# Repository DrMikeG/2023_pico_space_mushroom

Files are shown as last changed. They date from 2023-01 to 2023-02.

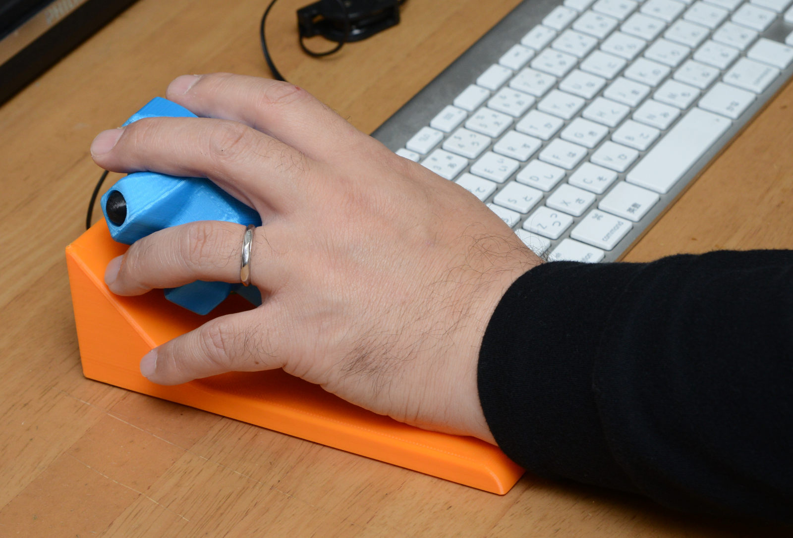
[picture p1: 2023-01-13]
Space_Mushroom___Full_6_DOFs_Space_Mouse_5739462/images/base1s.jpg

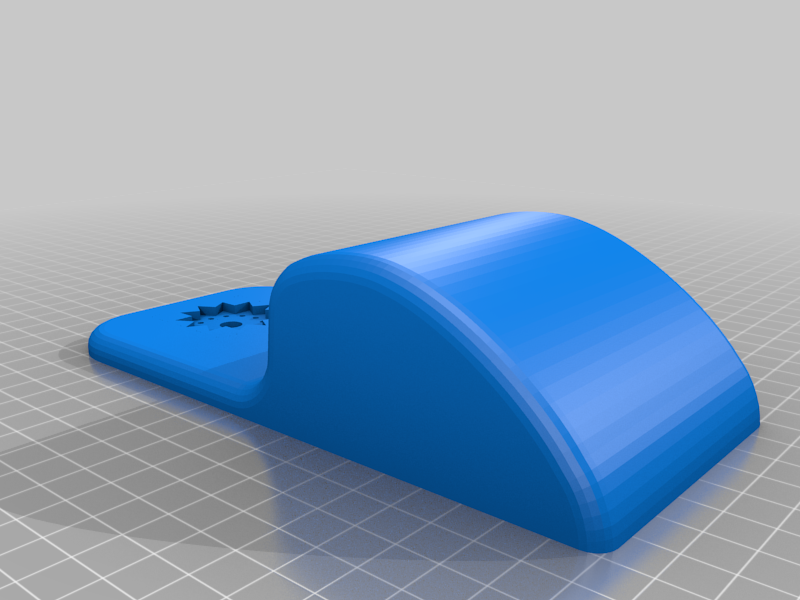
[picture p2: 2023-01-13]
Space_Mushroom___Full_6_DOFs_Space_Mouse_5739462/images/horizontal-base.png

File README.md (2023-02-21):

# 2023_pico_space_mushroom

https://www.thingiverse.com/thing:5739462

I've started printing the parts - beginning with the big knob.

I've ordered:

```WMYCONGCONG 5 PCS Joystick Breakout Module Game Controller for Arduino PS2 + 120 PCS Multicolored Breadboard Jumper Wires Ribbon Cables Kit```

Because I think they match the dimensions used by the OP.

```BGTXINGI 800PCS 8 Kinds M2 Nickel-Plate Flat Head Self Tapping Screw Stainless Sheet Wood Screw Assortment Kit Collected in A Convenient Case```

For assembly

And because I plan to use a pico, which only has 3 ADCs (and I need 6 inputs) - 

```SparkFun Analog/Digital MUX Breakout - CD74HC4067```

> This is a breakout board for the very handy 16-Channel Analog/Digital Multiplexer/Demultiplexer CD74HC4067. This chip is like a rotary switch - it internally routes the common pin (COM in the schematic, SIG on the board) to one of 16 channel pins (CHANxx).
>
> It works with both digital and analog signals (the voltage can’t be higher than VCC), and the connections function in either direction. To control it, connect 4 digital outputs to the chip’s address select pins (S0-S3), and send it the binary address of the channel you want (see the datasheet for details). This allows you to connect up to 16 sensors to your system using only 5 pins!
>
> Since the mux/demux also works with digital signals, you can use it to pipe TTL-level serial data to or from multiple devices. For example, you could use it to connect the TX pins of 16 devices to one RX pin on your microcontroller. You can then select any one of those 16 devices to listen to. If you want two-way communications, you can add a second board to route your microcontroller’s TX line to 16 device’s RX lines. By using multiple boards, you can create similar arrangements for I2C, SPI, etc.
>
> The internal switches are bidirectional, support voltages between ground and VCC, have low “on” resistance and low “off” leakage, and to prevent crosstalk, perform “break-before-make” switching. The board also breaks out the chip’s “enable” pin, which when driven high, will completely disconnect the common pin (all switches “off”).
>
> Features:
> 2V to 6V operation
> “On” resistance: 70 Ohms @ 4.5V
> 6ns break-before-make @ 4.5V
> Wide operating temperature range: -55C to 125C
> Documents:
> - https://www.sparkfun.com/datasheets/IC/cd74hc4067.pdf
> - https://github.com/sparkfun/Analog_Digital_MUX_Breakout

> Do note that the enable pin, EN, is active low. The description says this but I don't read...
> Use this to read sixteen inputs or to control sixteen outputs (or any combination thereof) using only six pins from you micro (five pins if you hold EN low via hardwire).

Let's go study the example code.

It acts as both a mouse and keyboard. Can the pico do this?

https://learn.adafruit.com/circuitpython-essentials/circuitpython-hid-keyboard-and-mouse

I wired up the joystick modules to the pico, and read the dx and dy values.

They seem are sensitive enough for left vs right, but the granularity seems very low, especially for higher values.
Also, pushing fully up seems to register as full up and full right. I've ordered some more.

Going to check one I've not soldered - perhaps the heat damaged the pots?
- No, warehouse soldered ones are just as crappy.

Wait for new supplies.

5 New, equally crappy looking joystick modules arrived. Same B103 pots. New boards don't even have the corners rounded off.
Got exactly the same behaviour when plugged in - considered that it could be because I was supplying 5V and then reading it with a 3V ADC.

Swapped power to joystick to 3V and they behave much more predictably. Hopefully my ADC is not damaged.

Pan in our app is
left-shift + middle mouse button press + mouse move up/down left/right

![Alt text](./readme_img/Raspberry-Pi-Pico-pinout-diagram.svg)

## Joystick failure ## 

I had a burnt out joystick module. The joystick was registering 3v3 on both axis all the time. Swapped it out.

## Mouse acceleration ##

Using 10_ and 11_ I figured out what I couldn't get the mouse to return the starting position.

Windows takes the instruction (10,24) and applies an acceleration factor so who knows what it might move by.

So, no hope of making it return to the starting position.

I did however learn the polling him for the USD HID is only 8ms - so I can probably reduce my delays quite a lot.

I also fixed a bug in deaden and using ceiling for negative numbers.

Now working on 12_

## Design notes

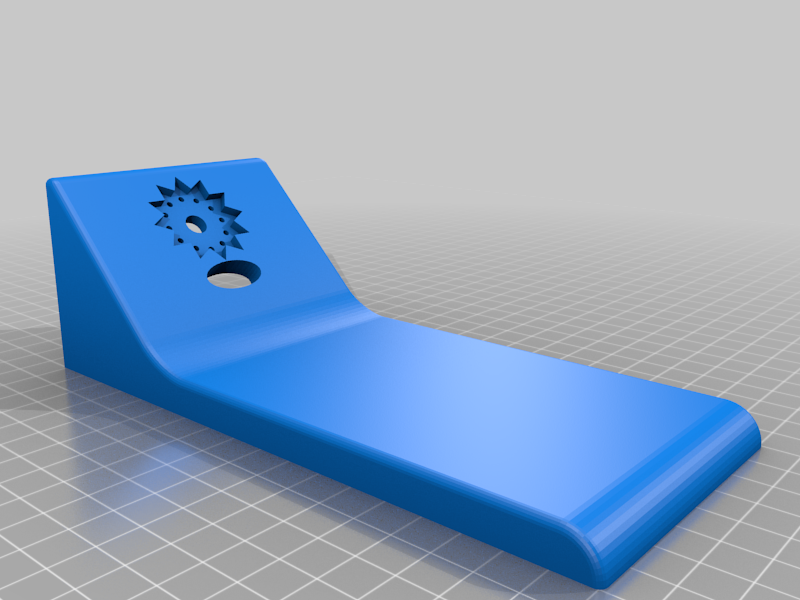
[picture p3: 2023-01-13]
Space_Mushroom___Full_6_DOFs_Space_Mouse_5739462/images/tilted-base.png

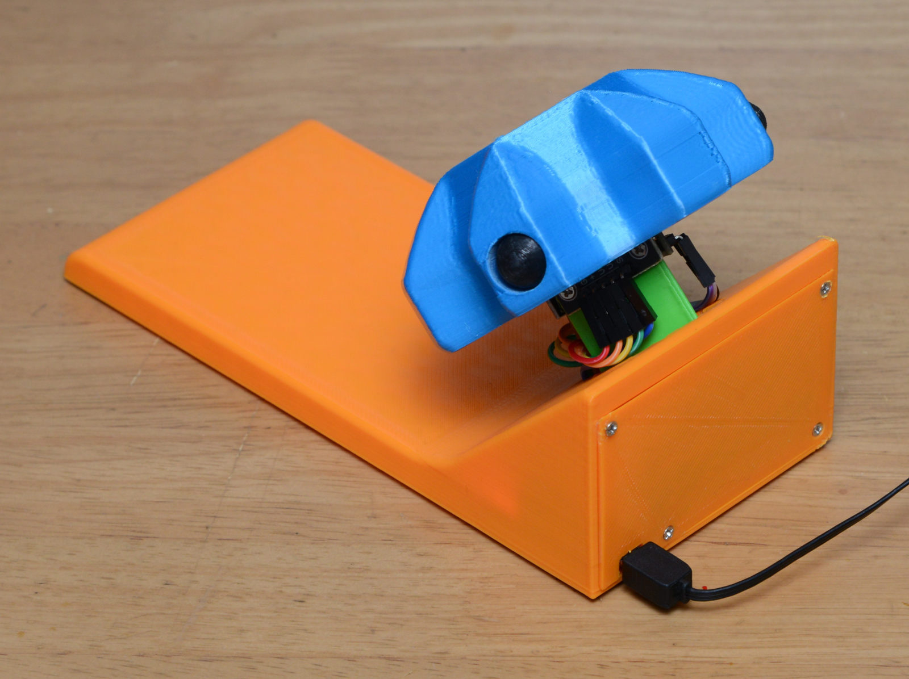
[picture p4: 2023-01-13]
Space_Mushroom___Full_6_DOFs_Space_Mouse_5739462/images/base4s.jpg

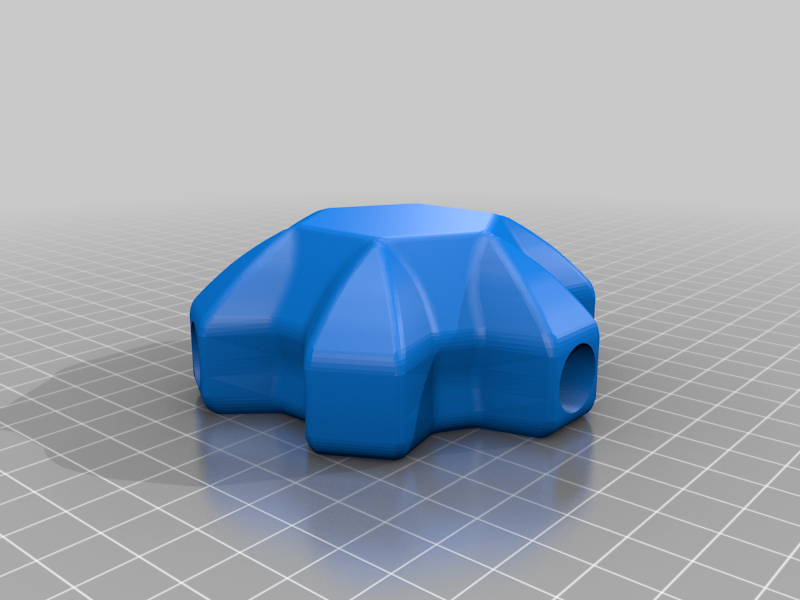
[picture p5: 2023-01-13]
Space_Mushroom___Full_6_DOFs_Space_Mouse_5739462/images/knob.png

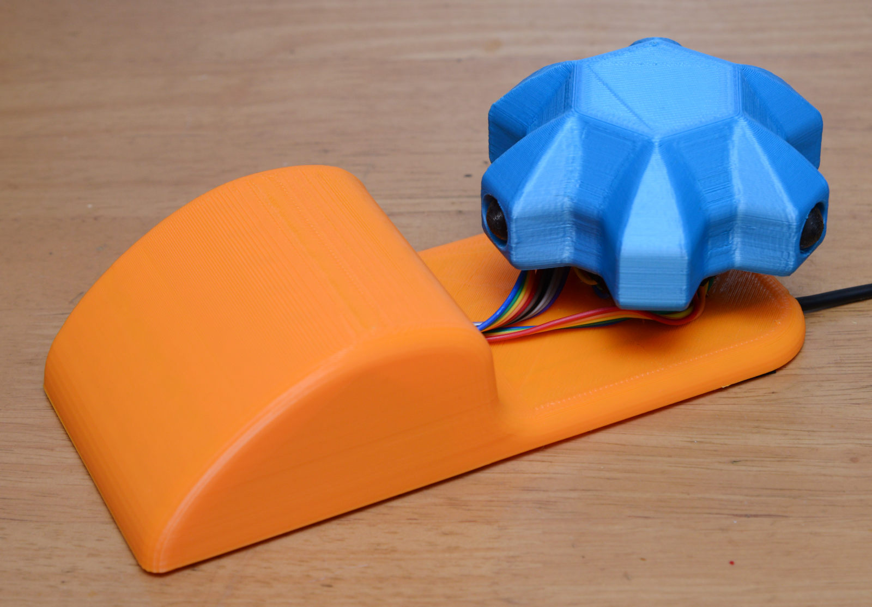
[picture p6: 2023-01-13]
Space_Mushroom___Full_6_DOFs_Space_Mouse_5739462/images/horizontal1s.jpg

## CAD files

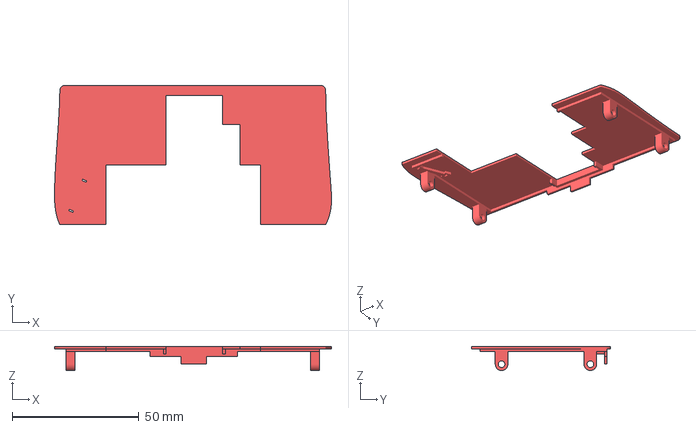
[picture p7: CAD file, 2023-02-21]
parts/mounting_lid_right_04.3mf
109.4 x 55.0 x 9.50 mm

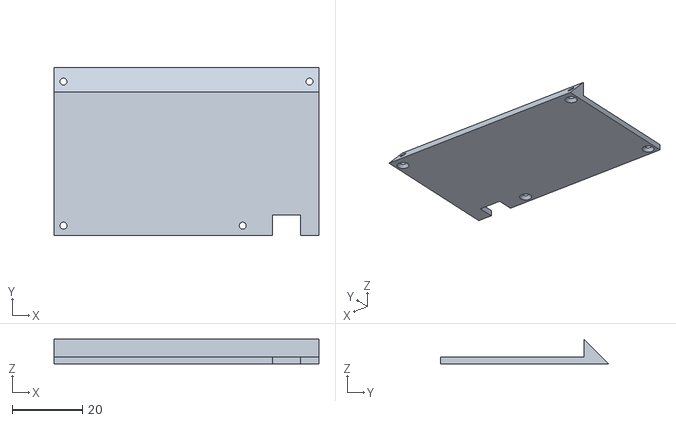
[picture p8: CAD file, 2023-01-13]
Space_Mushroom___Full_6_DOFs_Space_Mouse_5739462/files/tilted-rear-cover.stl
75.4 x 47.8 x 7.00

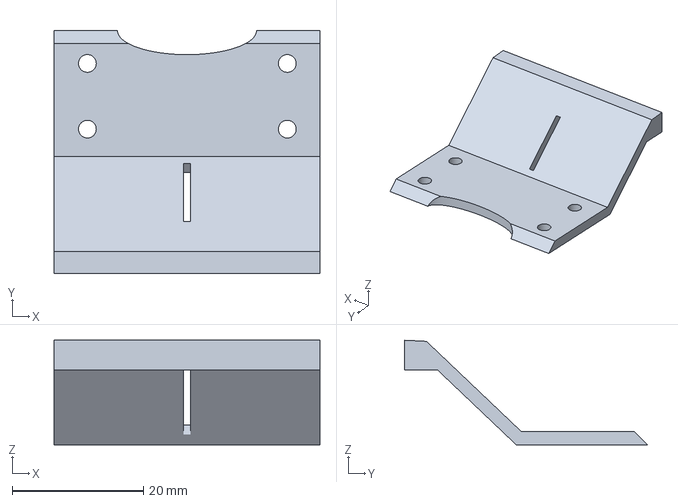
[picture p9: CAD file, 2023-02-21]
parts/mounting_facia_01.3mf
40.5 x 37.0 x 15.9 mm

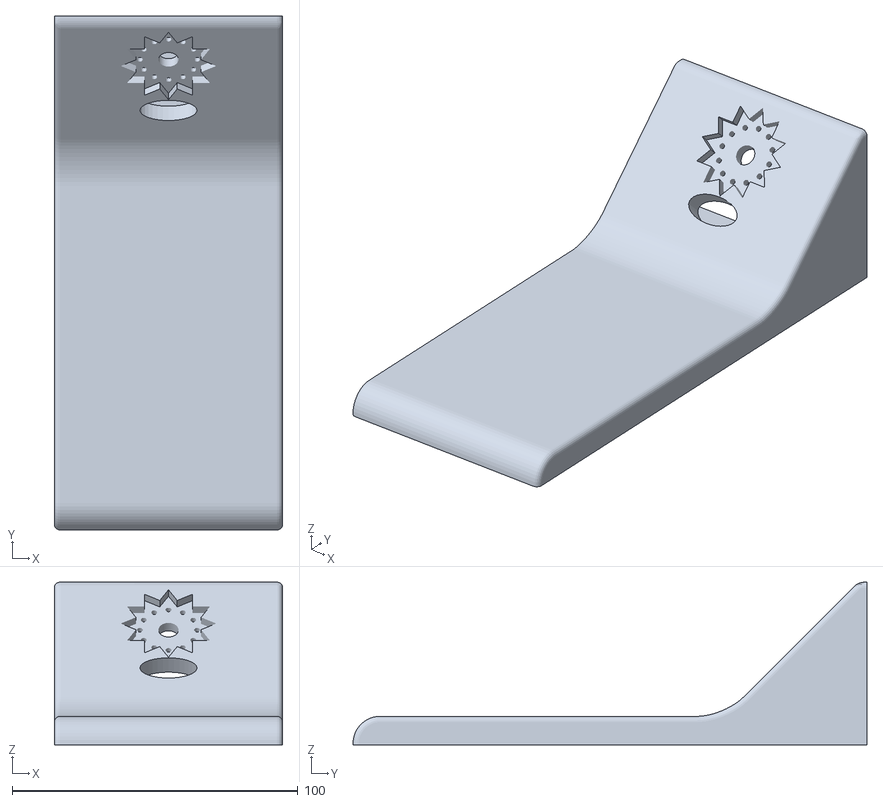
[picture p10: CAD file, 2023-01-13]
Space_Mushroom___Full_6_DOFs_Space_Mouse_5739462/files/tilted-base.stl
80.0 x 180.0 x 57.0

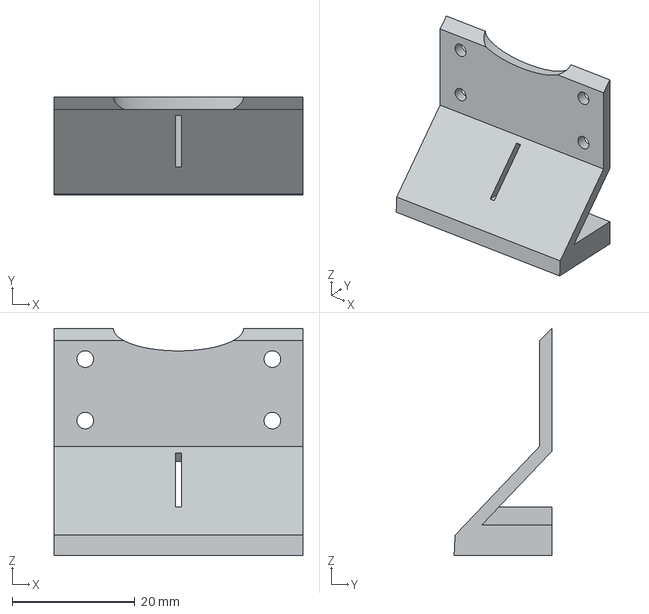
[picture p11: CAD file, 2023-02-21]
parts/mounting_facia_01_with_supports.3mf
40.5 x 15.9 x 37.0 mm

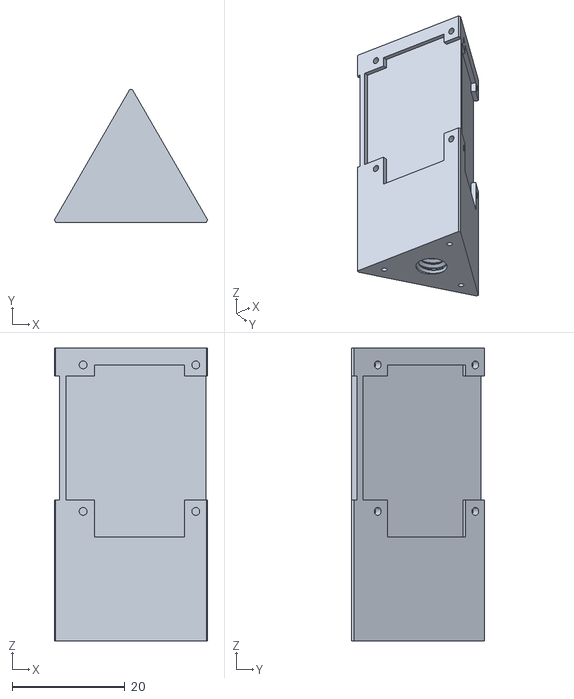
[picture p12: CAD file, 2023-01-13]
Space_Mushroom___Full_6_DOFs_Space_Mouse_5739462/files/shaft.stl
27.2 x 23.6 x 52.0

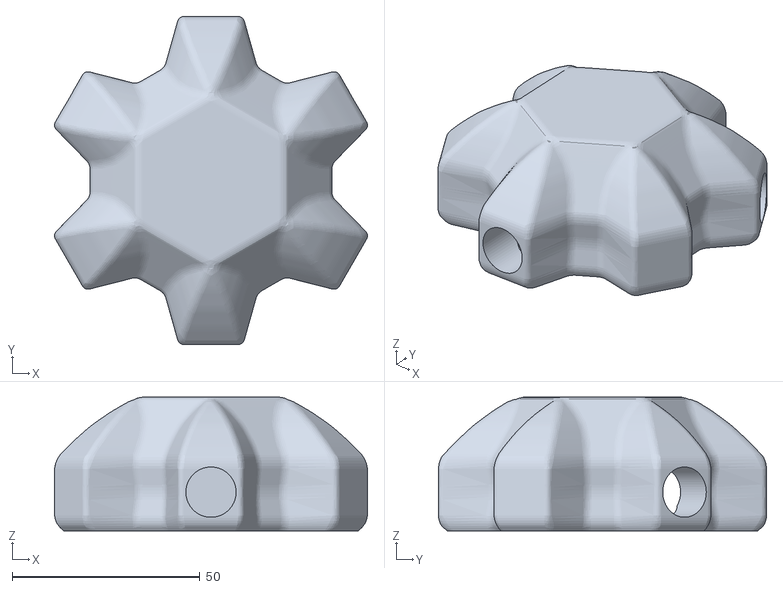
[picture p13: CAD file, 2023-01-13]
Space_Mushroom___Full_6_DOFs_Space_Mouse_5739462/files/knob.stl
83.4 x 87.4 x 35.6

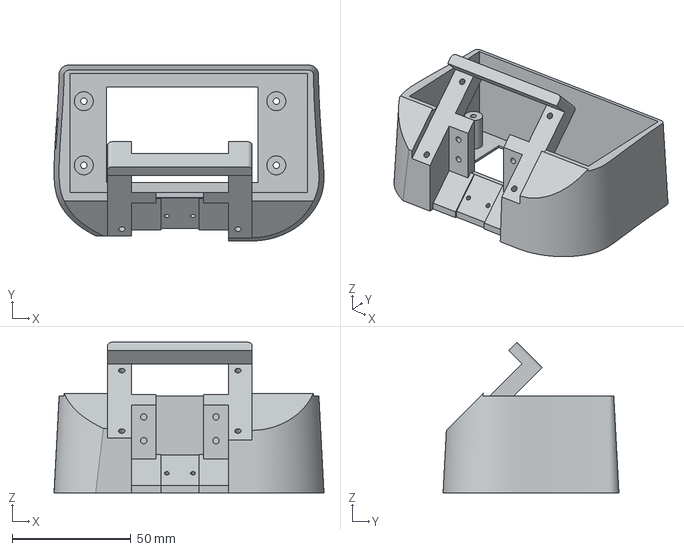
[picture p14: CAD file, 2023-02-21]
parts/mounting_subbase_05.3mf
113.7 x 74.1 x 63.4 mm

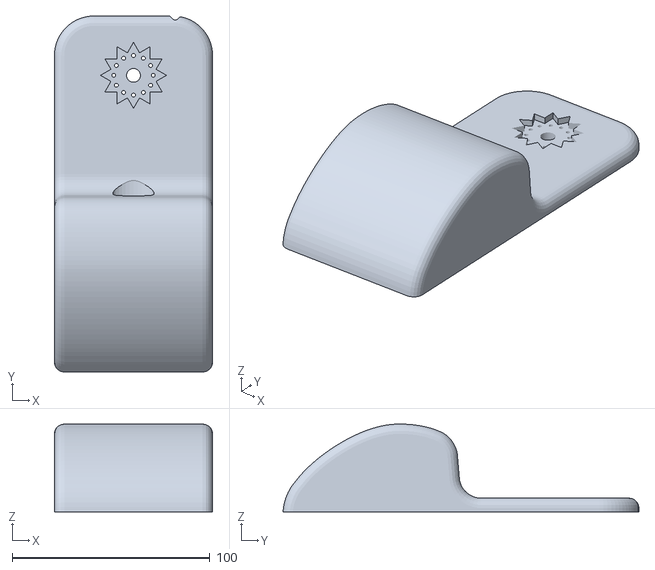
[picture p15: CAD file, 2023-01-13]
Space_Mushroom___Full_6_DOFs_Space_Mouse_5739462/files/horizontal-base.stl
80.0 x 180.0 x 44.4

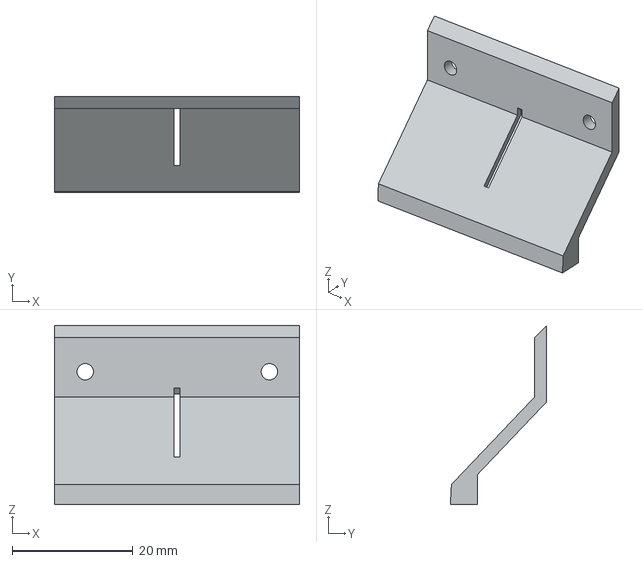
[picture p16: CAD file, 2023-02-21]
parts/mounting_facia_03.3mf
40.5 x 15.9 x 29.6 mm

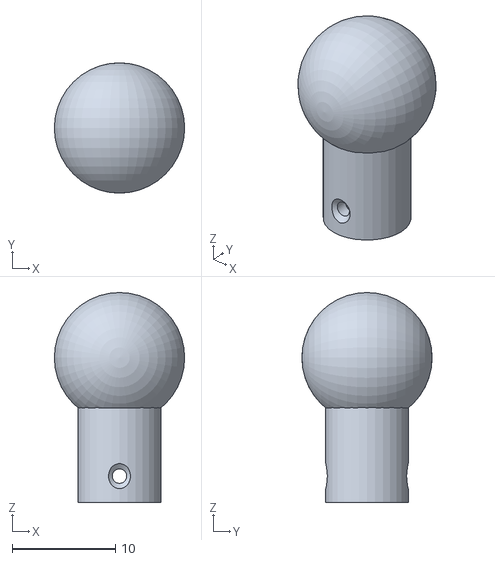
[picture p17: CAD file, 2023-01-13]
Space_Mushroom___Full_6_DOFs_Space_Mouse_5739462/files/ball-joint.stl
12.6 x 12.6 x 20.3

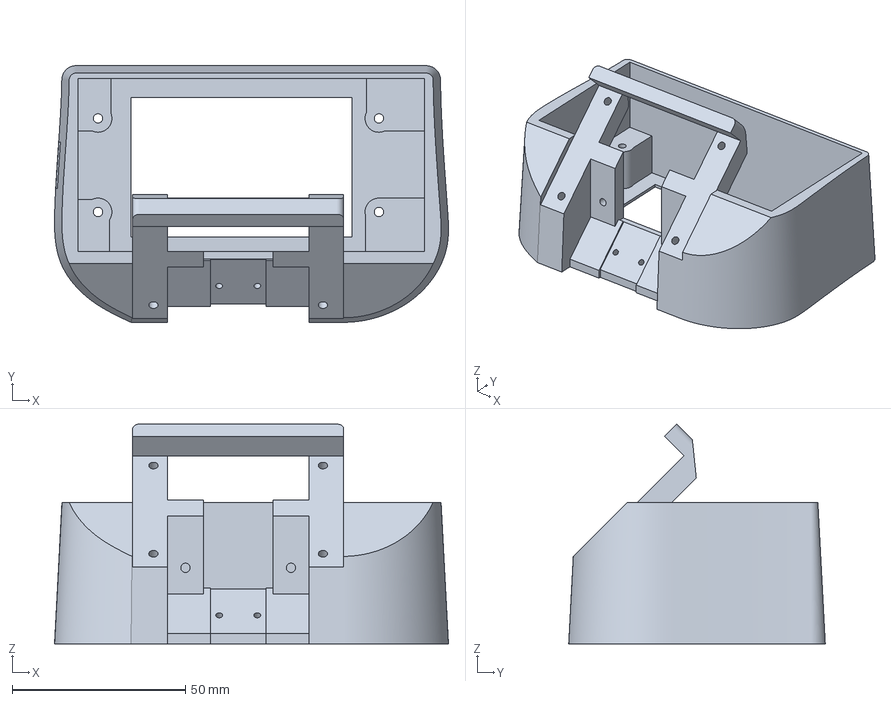
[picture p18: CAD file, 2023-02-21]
parts/mounting_subbase_06.3mf
113.7 x 74.1 x 63.4 mm

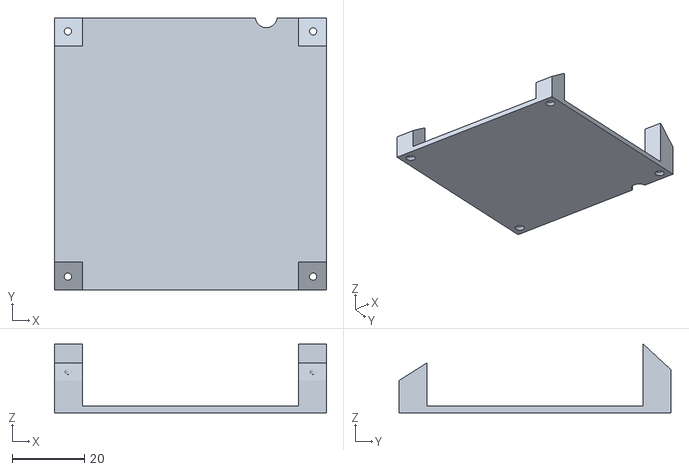
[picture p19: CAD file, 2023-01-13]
Space_Mushroom___Full_6_DOFs_Space_Mouse_5739462/files/horizontal-bottom-cover.stl
75.4 x 75.4 x 19.1

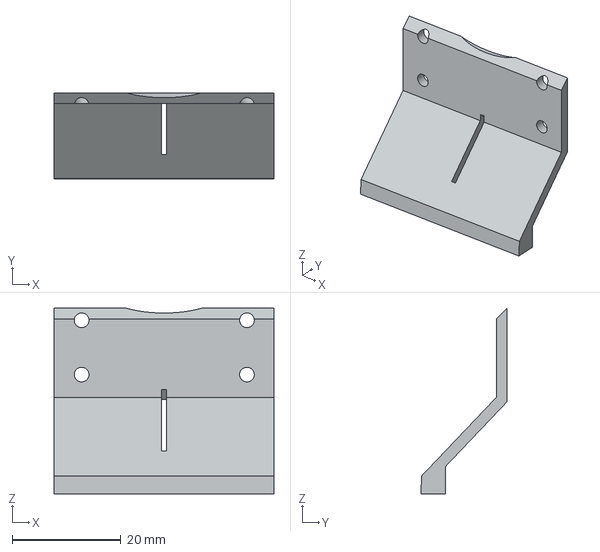
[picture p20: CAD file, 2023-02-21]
parts/mounting_facia_02.3mf
40.5 x 15.9 x 34.2 mm

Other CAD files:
parts/mounting_lid_right_05.3mf
parts/mounting_lid_right_03.3mf
parts/Mounting_ADC_layer_04.3mf
parts/mounting_subbase_01.3mf
NX_pump_x_t.prt
parts/Mounting_ADC_layer_02.3mf
parts/Mounting_ADC_layer_03.3mf
parts/Mounting_ADC_layer_06.3mf
parts/Mounting_ProtoLayer00_01.3mf
parts/Mounting_ProtoLayer00_02.3mf
parts/Mounting_ProtoLayer00_03.3mf
parts/Mounting_ProtoLayer01_01.3mf
parts/Mounting_ProtoLayer01_02.3mf
parts/Thumbstick.3mf
parts/Thumbstick_fine.3mf
parts/led_mount_01.3mf
parts/led_mount_03.3mf
parts/min_base_support_02.3mf
parts/minimal_base.stl
parts/minimal_base_remade.3mf
parts/mounting_feet_01.3mf
parts/mounting_lid_right_01.3mf
parts/mounting_lid_right_02.3mf
parts/mounting_subbase_02.3mf
parts/mounting_subbase_03.3mf
parts/mounting_subbase_04.3mf

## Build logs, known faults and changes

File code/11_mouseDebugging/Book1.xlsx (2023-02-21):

Intended Position |  | Intended Step
X | Y | Step X | Step Y
99 | 79
101 | 83 | 2 | 4
104 | 88 | 3 | 5
107 | 93 | 3 | 5
110 | 98 | 3 | 5
113 | 103 | 3 | 5
99 | 79 | -14 | -24
Observed Position |  | Observed Step
X | Y | Step X | Step Y
99 | 79
100 | 84 | 1 | 5
105 | 93 | 5 | 9
110 | 101 | 5 | 8
115 | 110 | 5 | 9
121 | 118 | 6 | 8
81 | 49 | -40 | -69

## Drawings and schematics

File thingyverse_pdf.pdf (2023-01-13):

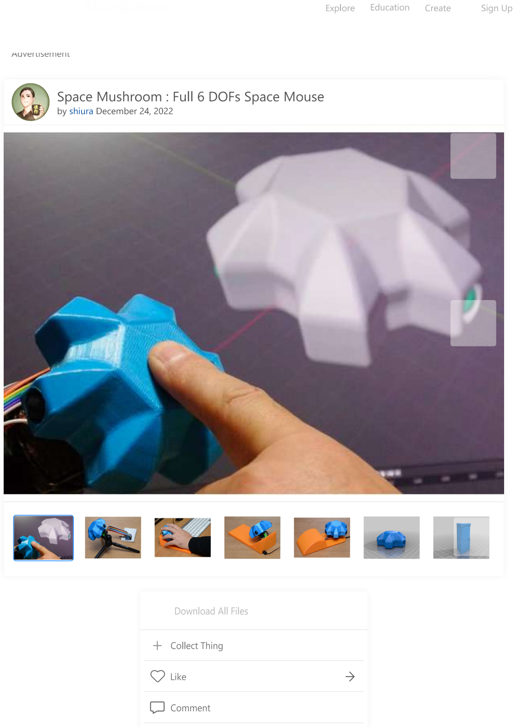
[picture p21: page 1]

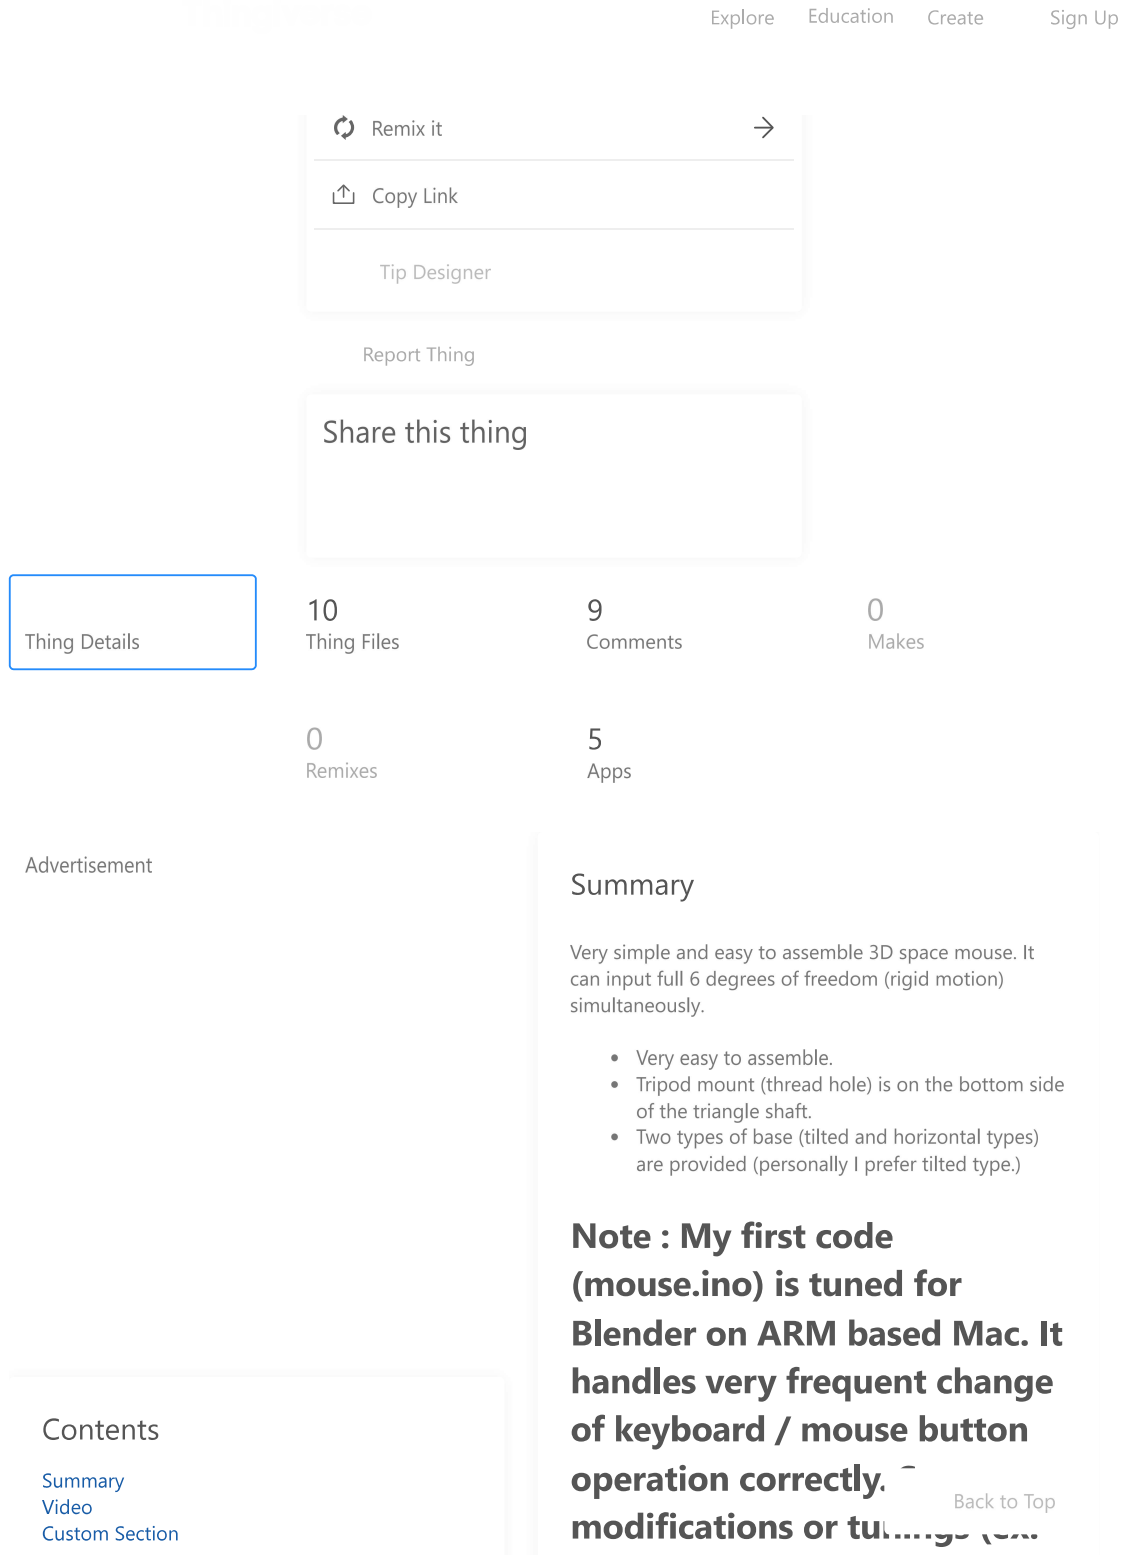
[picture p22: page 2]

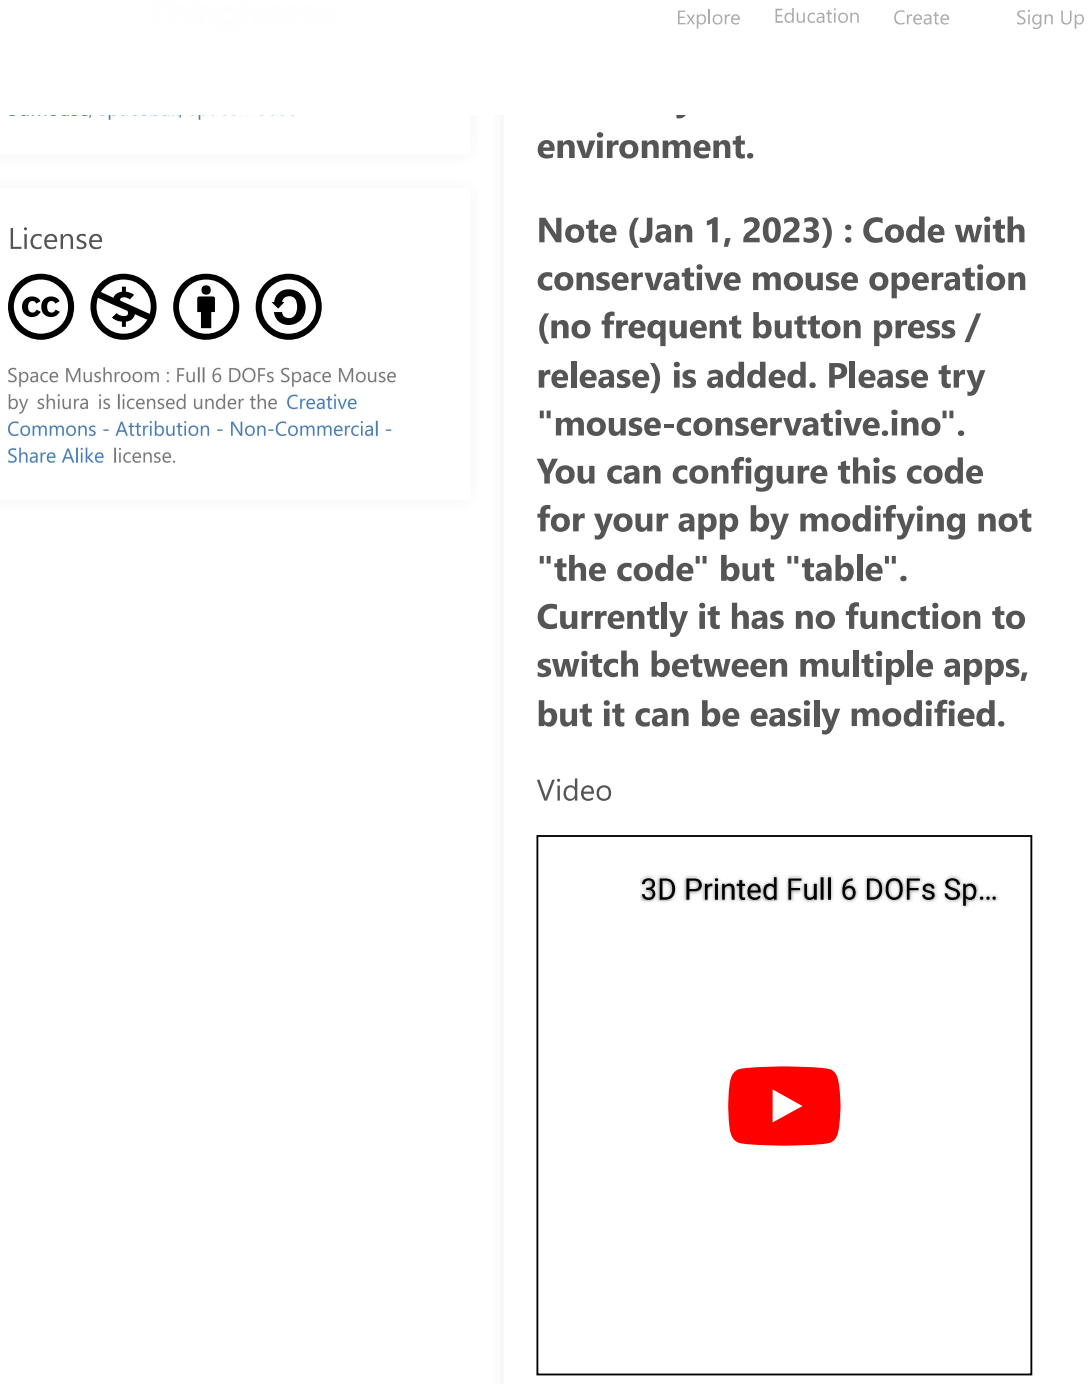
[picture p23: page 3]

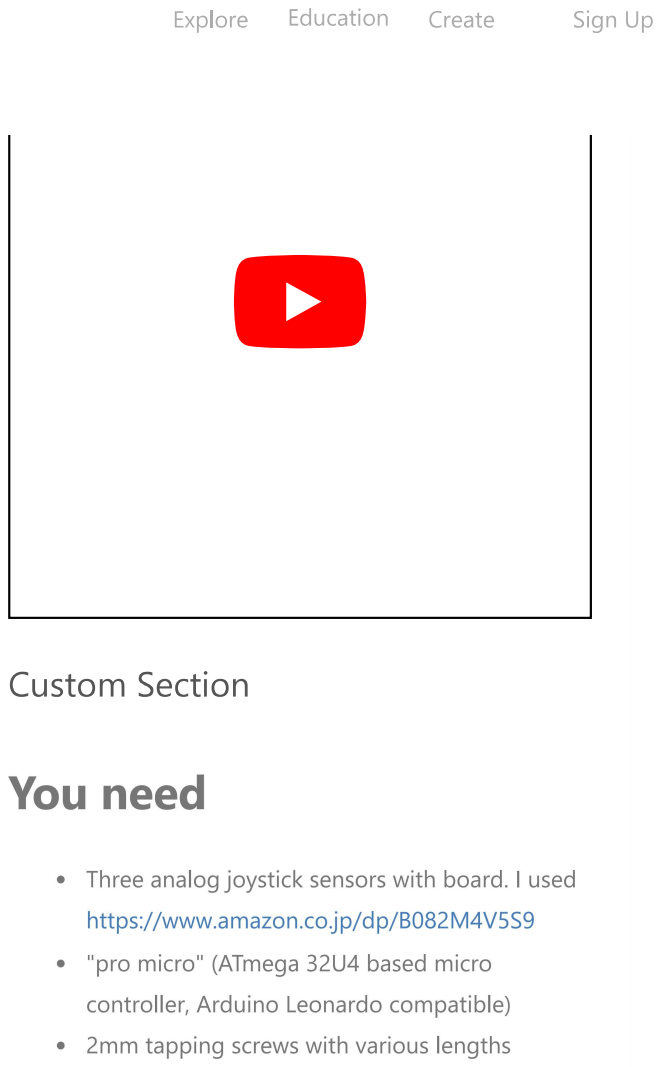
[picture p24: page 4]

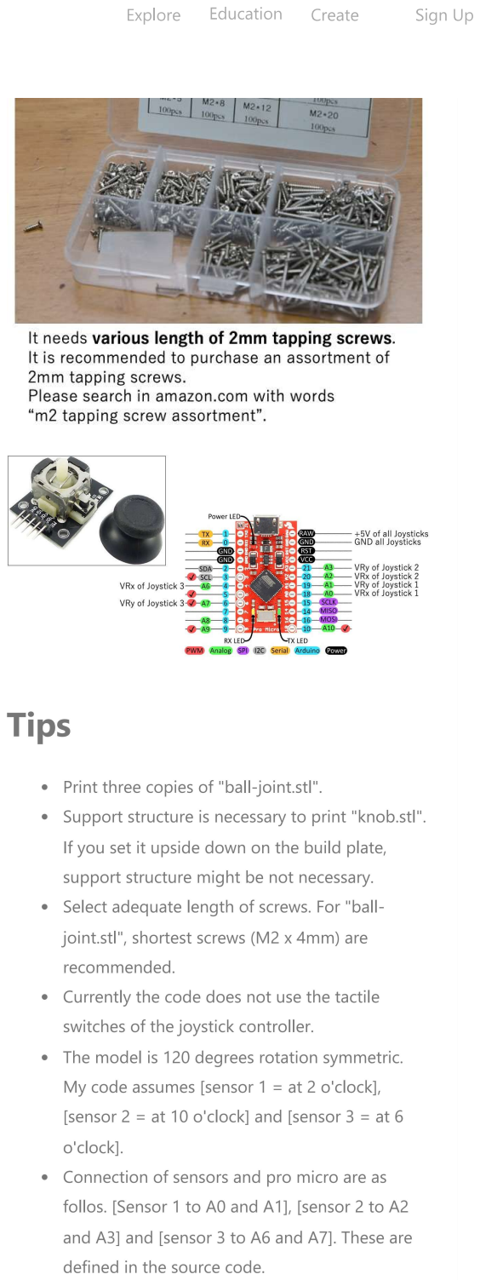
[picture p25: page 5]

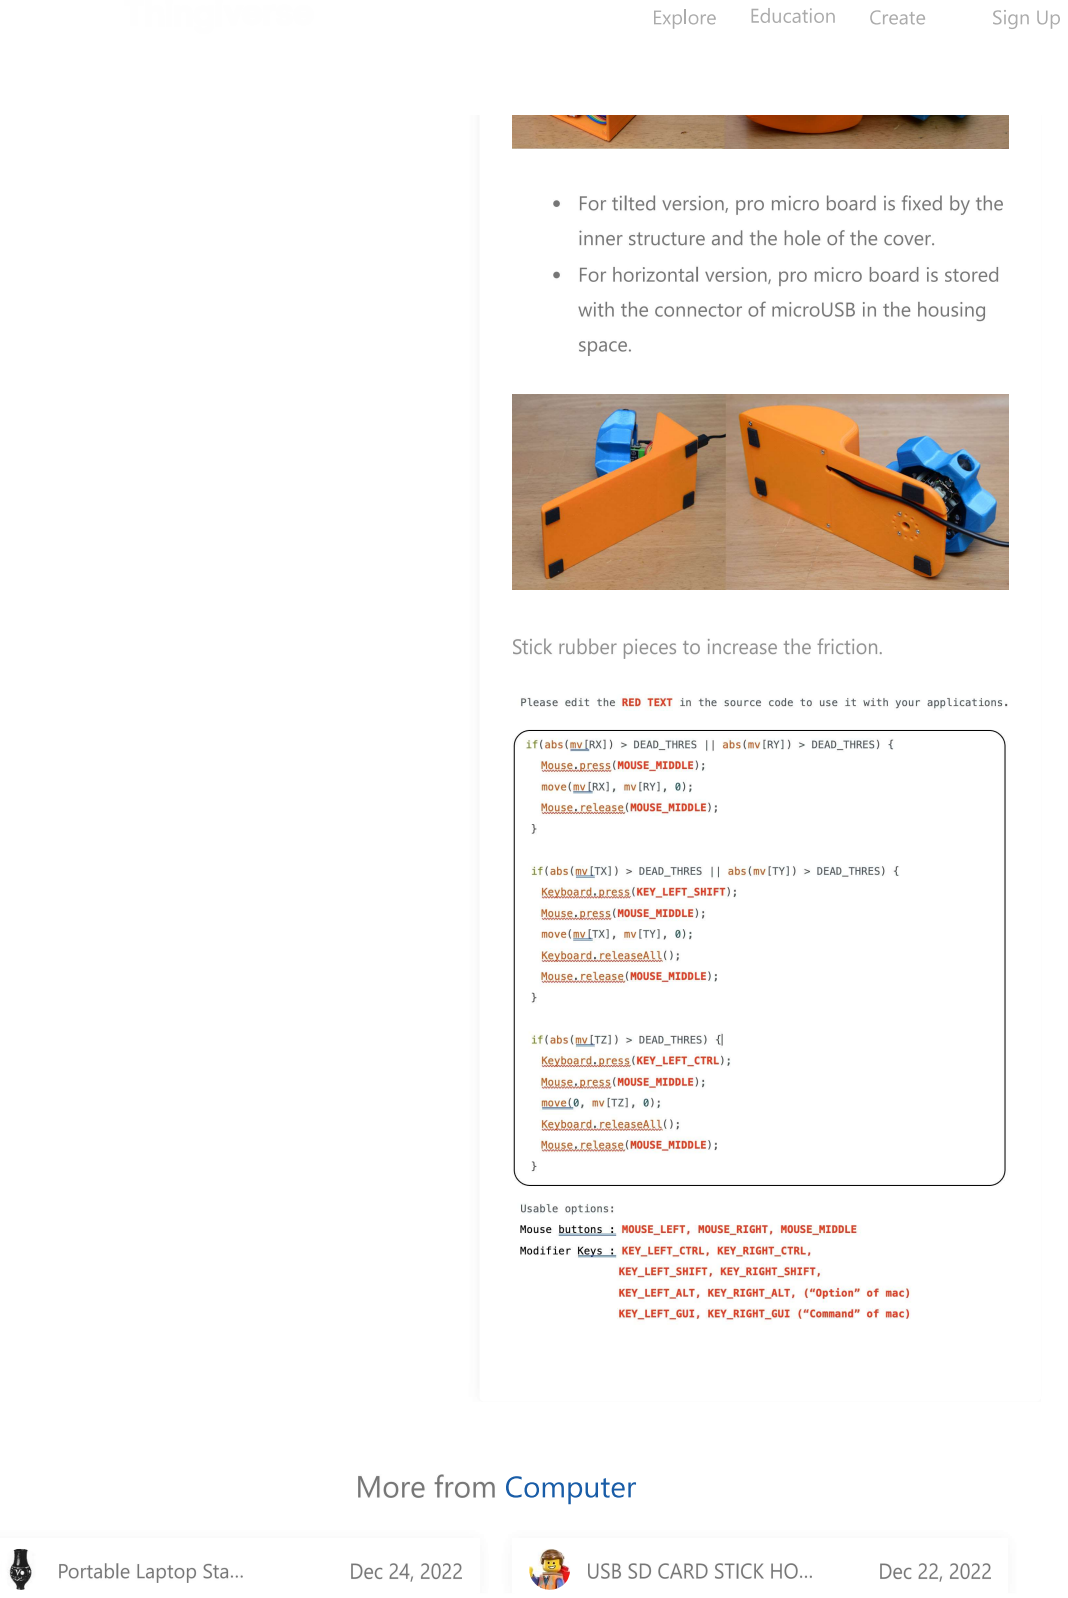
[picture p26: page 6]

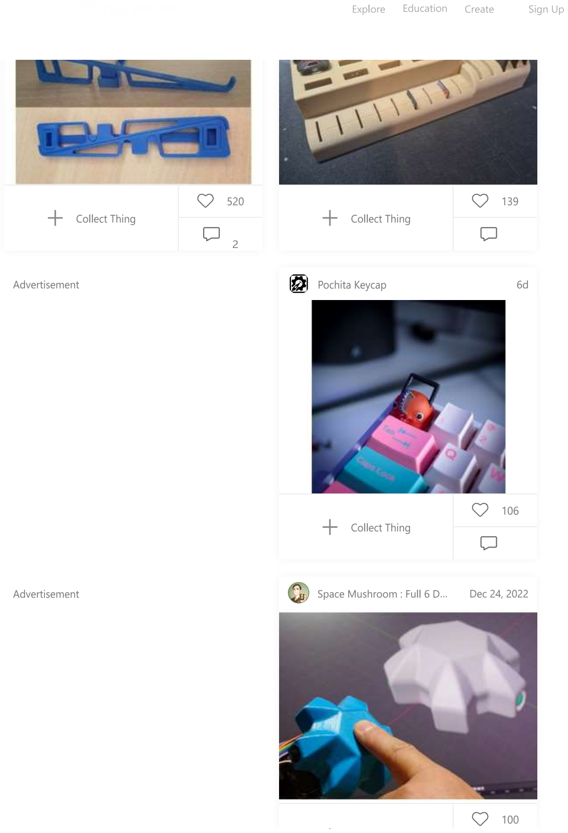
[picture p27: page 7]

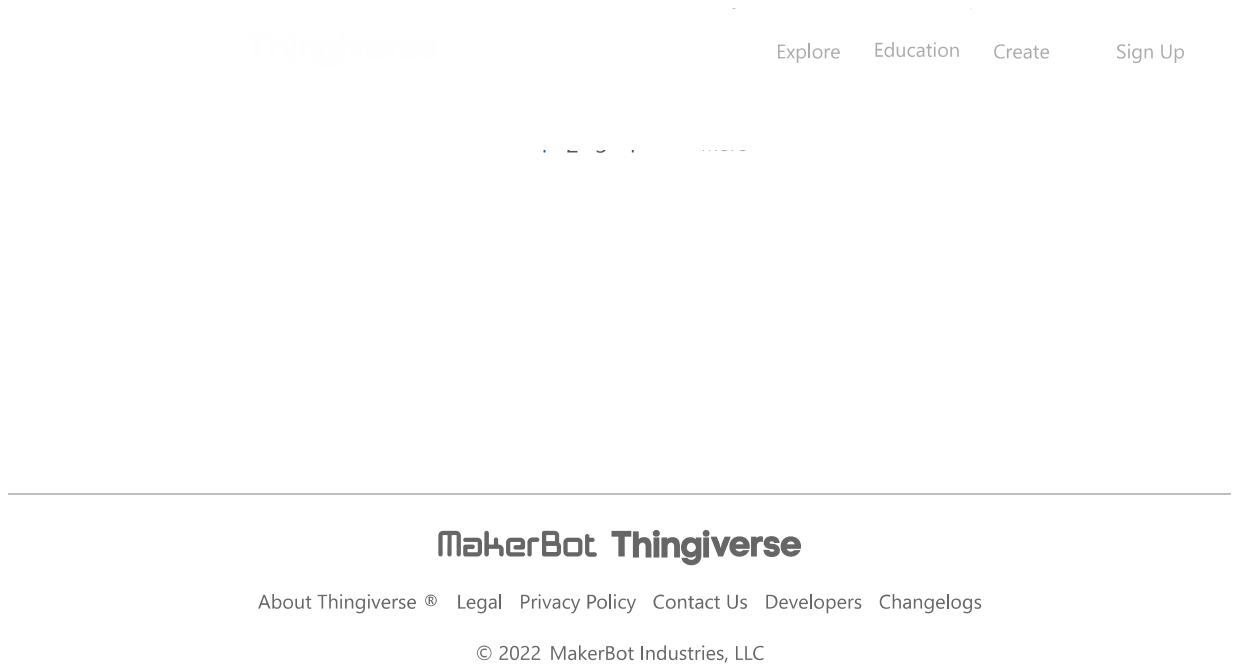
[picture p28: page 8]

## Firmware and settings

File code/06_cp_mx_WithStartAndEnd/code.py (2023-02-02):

import time
import board
from digitalio import DigitalInOut, Direction, Pull
import analogio
import math
import usb_hid
from adafruit_hid.keyboard import Keyboard
from adafruit_hid.keyboard_layout_us import KeyboardLayoutUS
from adafruit_hid.keycode import Keycode

keyboard = Keyboard(usb_hid.devices)
keyboard_layout = KeyboardLayoutUS(keyboard)  # We're in the US :)

adc = analogio.AnalogIn(board.GP27)

s0 = DigitalInOut(board.GP2)
s1 = DigitalInOut(board.GP3)
s2 = DigitalInOut(board.GP4)
s3 = DigitalInOut(board.GP5)
s0.direction = Direction.OUTPUT
s1.direction = Direction.OUTPUT
s2.direction = Direction.OUTPUT
s3.direction = Direction.OUTPUT

led = DigitalInOut(board.LED)
led.direction = Direction.OUTPUT
led.value = True

DOF = 6
TX = 0 # translation X -> pan X
TY = 1 # translation Y -> pan Y
TZ = 2 # translation Z -> zoom
RX = 3 # rotation X
RY = 4 # rotation Y
RZ = 5 # rotation Z

# [2,3]       [0,1]
#      \     /
#       \   /
#         |
#         |
#       [4,5]
# 2   0
#   *    left/right
#   4
#
# 3   1
#   *   up/down
#   5
# Reading the above number anti-clockwise 2 o'clock, 10 o'clock, 6 o'clock
PORTS = [1,5,3,0,4,2]

coeff = [
    [00.0, 00.0, 00.0, -10.0, -10.0, 20.0], # TX
    [00.0, 00.0, 00.0, -17.0,  17.0, 00.0], # TY
    [-4.0, -4.0, -4.0,  00.0,  00.0, 00.0], # TZ (zoom)
    [-6.0,  6.0, 00.0,  00.0,  00.0, 00.0], # RY
    [ 3.0,  3.0, -6.0,  00.0,  00.0, 00.0], # RX
    [00.0, 00.0, 00.0,  03.0,  03.0, 03.0]  # RZ (not used)
]

origin = []
sx = 0
sy = 0
sw = 0

# The analog reading on the pin. Although it is limited to the resolution of the analog to digital converter (0-1023 for 10 bits or 0-4095 for 12 bits). Data type: int.
# 9 channels of 10-bit ADC

def blink(times):
    for _ in range(times):
        led.value = False
        time.sleep(0.1)
        led.value = True
        time.sleep(0.1)

def switchMX(cValue):
    if cValue == 0:
        # 0000
        s3.value = False
        s2.value = False
        s1.value = False
        s0.value = False
    elif cValue == 1:
        # 0001
        s3.value = False
        s2.value = False
        s1.value = False
        s0.value = True
    elif cValue == 2:
        # 0010
        s3.value = False
        s2.value = False
        s1.value = True
        s0.value = False
    elif cValue == 3:
        # 0011
        s3.value = False
        s2.value = False
        s1.value = True
        s0.value = True
    elif cValue == 4:
        # 0100
        s3.value = False
        s2.value = True
        s1.value = False
        s0.value = False
    elif cValue == 5:
        # 0101
        s3.value = False
        s2.value = True
        s1.value = False
        s0.value = True
    elif cValue == 6:
        # 0110
        s3.value = False
        s2.value = True
        s1.value = True
        s0.value = False
    elif cValue == 7:
        # 0111
        s3.value = False
        s2.value = True
        s1.value = True
        s0.value = True
    elif cValue == 8:
        # 1000
        s3.value = True
        s2.value = False
        s1.value = False
        s0.value = False
    #print(adc.value)

def isSwitch0():
    # enable checking of C6
    switchMX(6)
    return adc.value < 500

def isSwitch1():
    # enable checking of C7
    switchMX(7)
    return adc.value < 500

def isSwitch2():
    # enable checking of C8
    switchMX(8)
    return adc.value < 500

def readMux(cValue):
    switchMX(cValue)
    return adc.value

def mapValue(val,midVal):
    # assuming max of 64000
    # assuming min of 0
    # midVal is given
    # return values are -3, -2, -1, 0, 1, 2 or 3
    lowBox = (midVal / 10.0)
    if val < 3*lowBox:
        return -3
    if val < 6*lowBox:
        return -2
    if val < 9*lowBox:
        return -1
    if val < 10*lowBox:
        return 0
    highBox = (65536-midVal) / 10.0
    if val < midVal + (1 * highBox):
        return 0
    if val < midVal + (4 * highBox):
        return 1
    if val < midVal + (7 * highBox):
        return 2
    return 3

def deaden(val):
    if val > DEAD_THRESH:
        val = val - DEAD_THRESH
    elif val < DEAD_THRESH:
        val = val + DEAD_THRESH
    else:
        val = 0
    return val

def clamp(val):
    if val > 127:
        return 127
    elif val < -128:
        return -128
    return val

def setup():
    for p in range(DOF):
        port = PORTS[p]
        vals = []
        nSamples = 10
        for _ in range(nSamples):
            vals.append(readMux(port))
        origin.append(round(sum(vals)/nSamples))
        print("port {}: {} samples as vals {} averaged to {}".format(p,nSamples,vals,origin[p]))

# I though the original values were -128 - 127 (256) and mine were -32000 - +32000
# The original values were -512 - + 512
DEAD_THRESH = 1    # original value was 1
SPEED_PARAM = 5 # original value was 600

setup()

def isRotate(mv):
    return abs(mv[RX]) > DEAD_THRESH or abs(mv[RY]) > DEAD_THRESH 


def isTranslate(mv):
    return abs(mv[TX]) > DEAD_THRESH or abs(mv[TY]) > DEAD_THRESH 

def isZoom(mv):
    return abs(mv[TZ]) > DEAD_THRESH

def printSV(sv):
    #print("RX/RY : {},{}".format(mv[RX],mv[RY]))
    print("sv: {}".format(sv))

def printMV(mv):
    print("TX/TY : {},{}".format(mv[TX],mv[TY]))
    print("TZ : {}".format(mv[TZ]))
    #print("RX/RY : {},{}".format(mv[RX],mv[RY]))


# Have we started a movement?
isMouseMoving = False
# This will cause the mouse position to reset
shouldEndMove = False

while True:

    sv = [] # sensor values
    mv = [] # motion vector

    # Values are read and simply mapped -3 to +3
    for p in range(DOF):
        sv.append(mapValue(readMux(PORTS[p]),origin[p]))

    for i in range(DOF):
        mv.append(0.0)
        for j in range(DOF):
            mv[i] = mv[i] + (coeff[i][j] * sv[j])
        mv[i] = mv[i] / SPEED_PARAM
        # I doubt this is having any effect

    movementDetected = isRotate(mv) or isTranslate(mv) or isZoom(mv)
    
    if movementDetected:
        if not isMouseMoving: # if we were not moving, we now are
            isMouseMoving = True
            print("Starting movement...")
            # Start move (Init mouse? Press Key?)
    else:
        if isMouseMoving: # if we were moving, now we are not, and we should end
            isMouseMoving = False
            shouldEndMove = True

    # Do the app for now...
    isSE = False

    if isMouseMoving:
        if isRotate(mv):
            #print("Rotate RX/RY : {},{}".format(mv[RX],mv[RY]))
                # App key press to rotate is arrow keys
                # SE key press to rotate is arrow keys
                if mv[RX] > 0:
                    keyboard.send(Keycode.RIGHT_ARROW)
                elif mv[RX] < 0:             
                    keyboard.send(Keycode.LEFT_ARROW)
                if mv[RY] > 0:
                    keyboard.send(Keycode.DOWN_ARROW)
                elif mv[RY] < 0:             
                    keyboard.send(Keycode.UP_ARROW)
            
        if isTranslate(mv):
            print("Translating TX/TY : {},{}".format(mv[TX],mv[TY]))
            if isSE:
                keyboard.release(Keycode.LEFT_SHIFT)
                keyboard.press(Keycode.LEFT_CONTROL)
                if mv[TX] > 0:
                    keyboard.press(Keycode.RIGHT_ARROW)
                elif mv[TX] < 0:             
                    keyboard.press(Keycode.LEFT_ARROW)
                if mv[TY] > 0:
                    keyboard.press(Keycode.DOWN_ARROW)
                elif mv[TY] < 0:             
                    keyboard.press(Keycode.UP_ARROW)    
                keyboard.release_all()
            else:
                if mv[TX] > 0:
                    keyboard.press(Keycode.LEFT_SHIFT, Keycode.RIGHT_ARROW)
                elif mv[TX] < 0:             
                    keyboard.press(Keycode.LEFT_SHIFT, Keycode.LEFT_ARROW)
                if mv[TY] > 0:
                    keyboard.press(Keycode.LEFT_SHIFT, Keycode.DOWN_ARROW)
                elif mv[TY] < 0:             
                    keyboard.press(Keycode.LEFT_SHIFT, Keycode.UP_ARROW)

        if isZoom(mv):
            print("Zoom TZ: {}".format(mv[TZ]))
            if isSE:
                if mv[TZ] > 0:
                    keyboard.send(Keycode.RIGHT_CONTROL,Keycode.UP_ARROW)
                elif mv[TZ] < 0:             
                    keyboard.press(Keycode.RIGHT_CONTROL,Keycode.LEFT_ARROW)
            else:
                if mv[TZ] > 0:
                    keyboard.press(Keycode.PAGE_UP)
                elif mv[TZ] < 0:             
                    keyboard.press(Keycode.PAGE_DOWN)
    
    if shouldEndMove:
        keyboard.release_all()
        print("Ending movement...")
        time.sleep(0.1)
        shouldEndMove = False

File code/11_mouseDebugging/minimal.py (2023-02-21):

import time
import math
import usb_hid
from adafruit_hid.mouse import Mouse
import sys


mouse = Mouse(usb_hid.devices)

def move(x, y, w, sx, sy, sw):
    
    
    print("Moving {},{},{}".format(x,y,w))
    sx = sx + x
    sy = sy + y
    sw = sw + w
    mouse.move(x, y,w)
    print("Cumulative Move {},{},{}".format(sx,sy,sw))
    return sx, sy, sw

def resetMove(sx,sy,sw):
    print("Reset by moving {},{},{}".format(-sx,-sy,0))
    mouse.move(-sx, -sy, 0)
    return 0,0,0

try:
    print("Position your mouse somewhere for reference... movement will start in 5 seconds...")
    time.sleep(5)
    sx = 0
    sy = 0
    sw = 0
    #Moving 2,4,0
    print("Step 1 of 5")
    sx,sy,sw = move(2,4,0,sx,sy,sw)
    time.sleep(1.5)
    #Cumulative Move 2,4,0
    #Moving 3,5,0
    print("Step 2 of 5")
    sx,sy,sw = move(3,5,0,sx,sy,sw)
    time.sleep(1.5)
    #Cumulative Move 5,9,0
    #Moving 3,5,0
    print("Step 3 of 5")
    sx,sy,sw = move(3,5,0,sx,sy,sw)
    time.sleep(1.5)
    #Cumulative Move 8,14,0
    #Moving 3,5,0
    print("Step 4 of 5")
    sx,sy,sw = move(3,5,0,sx,sy,sw)
    time.sleep(1.5)
    #Cumulative Move 11,19,0
    #Moving 3,5,0
    print("Step 5 of 5")
    sx,sy,sw = move(3,5,0,sx,sy,sw)
    time.sleep(1.5)
    #Cumulative Move 14,24,0
    #Reset by moving -14,-24,0
    print("Return to starting position?")
    sx,sy,sw = resetMove(14,24,sw)
    time.sleep(1.3)
    
except:
    mouse.release_all()
    print(sys.exc_info()[0])



121,118
-14,-24
---
107,94

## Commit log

2023-01-13 Early work
    [Thumbstick.3mf, Thumbstick_fine.3mf, ball-joint.stl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]
2023-01-17 moving parts
    [Thumbstick.3mf, Thumbstick_fine.3mf, min_base_support_02.3mf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]
2023-01-17 02_cp is panning in the app, when switch 0 is clicked
2023-02-02 Numerous software revisions
    [NX_pump_x_t.prt, led_mount_01.3mf, led_mount_03.3mf]
2023-02-15 Saving a loads of modelling changes
    [Asm1.cfg, Mounting_ADC_layer_02.3mf, Mounting_ADC_layer_03.3mf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]
2023-02-21 More parts - fixed bugs in code
    [Book1.xlsx, mounting_facia_01.3mf, mounting_facia_01_with_supports.3mf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]
2023-02-21 saved change to current lid.
